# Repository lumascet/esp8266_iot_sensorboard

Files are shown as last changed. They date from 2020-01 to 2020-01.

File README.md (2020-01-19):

# Esp8266 IOT Sensorboard
A IOT Device with lots of sensors publishing acquired data via MQTT with automatic Home Assistant integration.
The board is equipped with following key components: 

* MQ Gas Sensors
    * MQ-3 Alcohol
    * MQ-4 CH4, LPG
    * MQ-7 CO
    * MQ-8 H2
    * MQ-135 Air-Quality
* BME280 Barometric Pressure, Temperature & Humidity
* GMYL8511 UV sensor
* GP2Y1010AU0F Sharp Dust Sensor
* Generic PIR Sensor
* Generic Microphone
* 5528 LDR
* PCF8574 I2C Port Expander
* ADS1115 16 bit ADC
* 74HC4051 8 channel Multiplexer

can be expanded with any other analog or i2c sensors.

Supports ESP8266 Boards NodeMCU & WeMos D1 mini

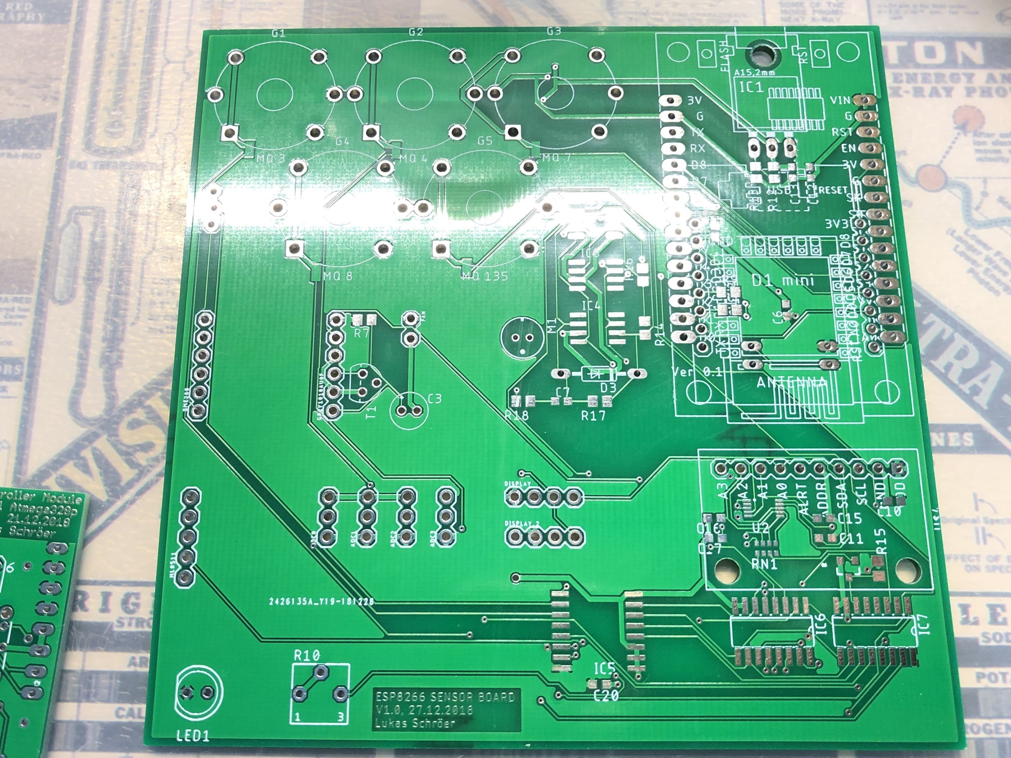
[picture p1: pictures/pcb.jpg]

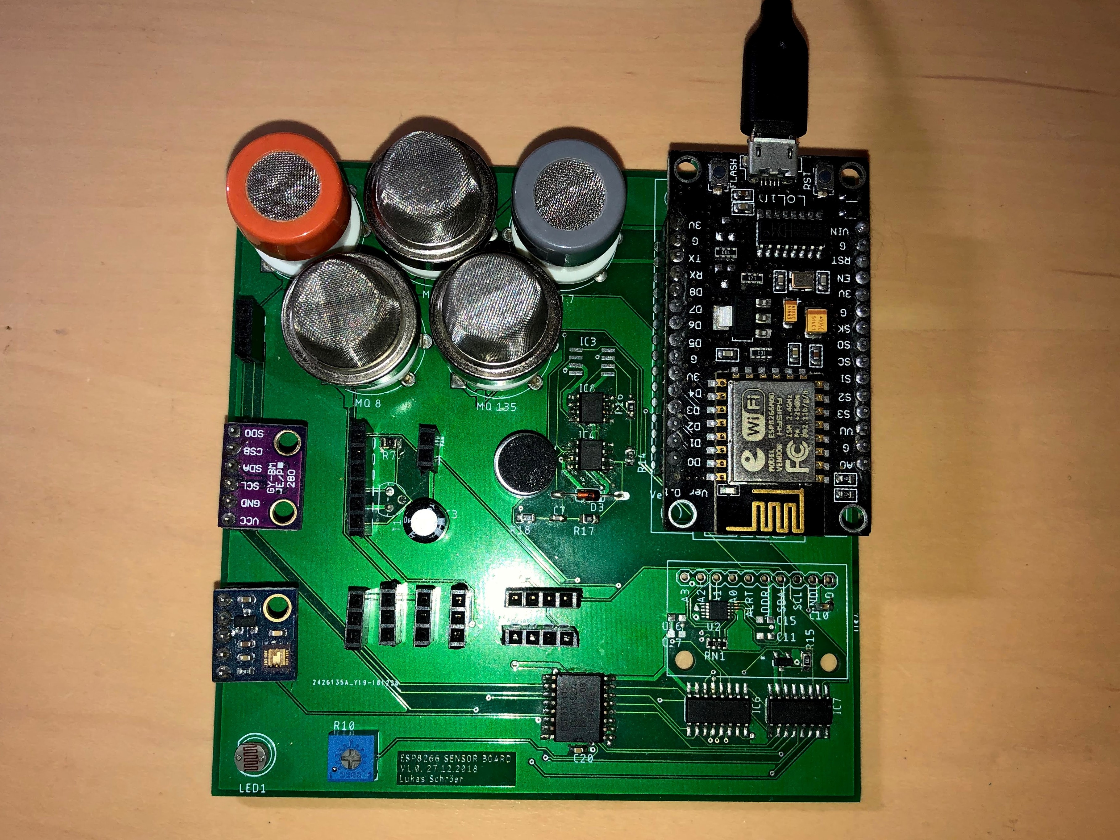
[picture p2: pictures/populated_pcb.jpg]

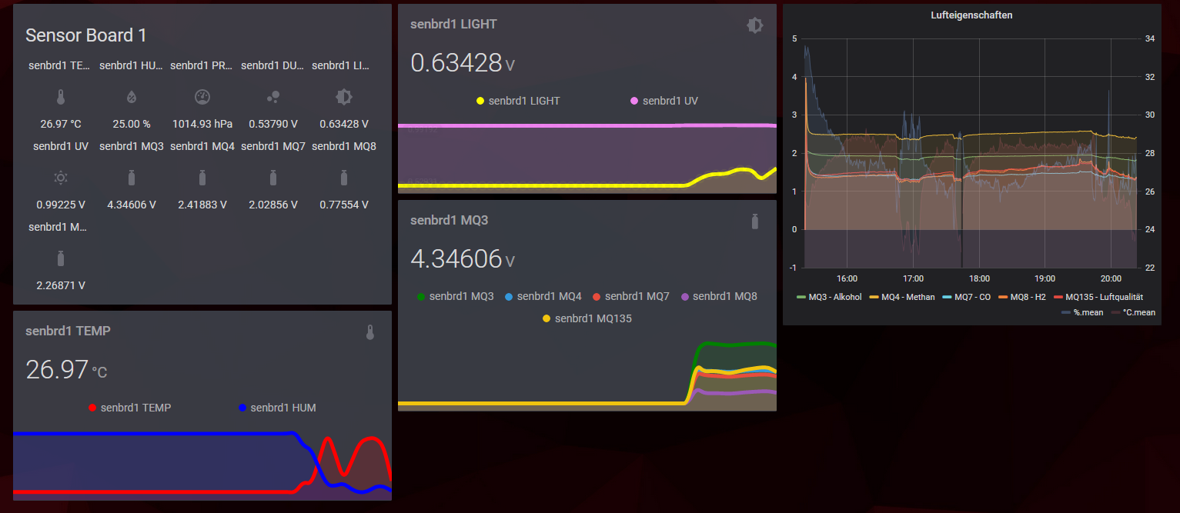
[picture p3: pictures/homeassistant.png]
Homeassistant


# Installation # 

just run the Platformio build task.

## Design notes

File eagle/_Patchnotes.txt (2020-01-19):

-Node MCU changed VIN to VV for 5V Rail
-BME280 too close to gas sensors

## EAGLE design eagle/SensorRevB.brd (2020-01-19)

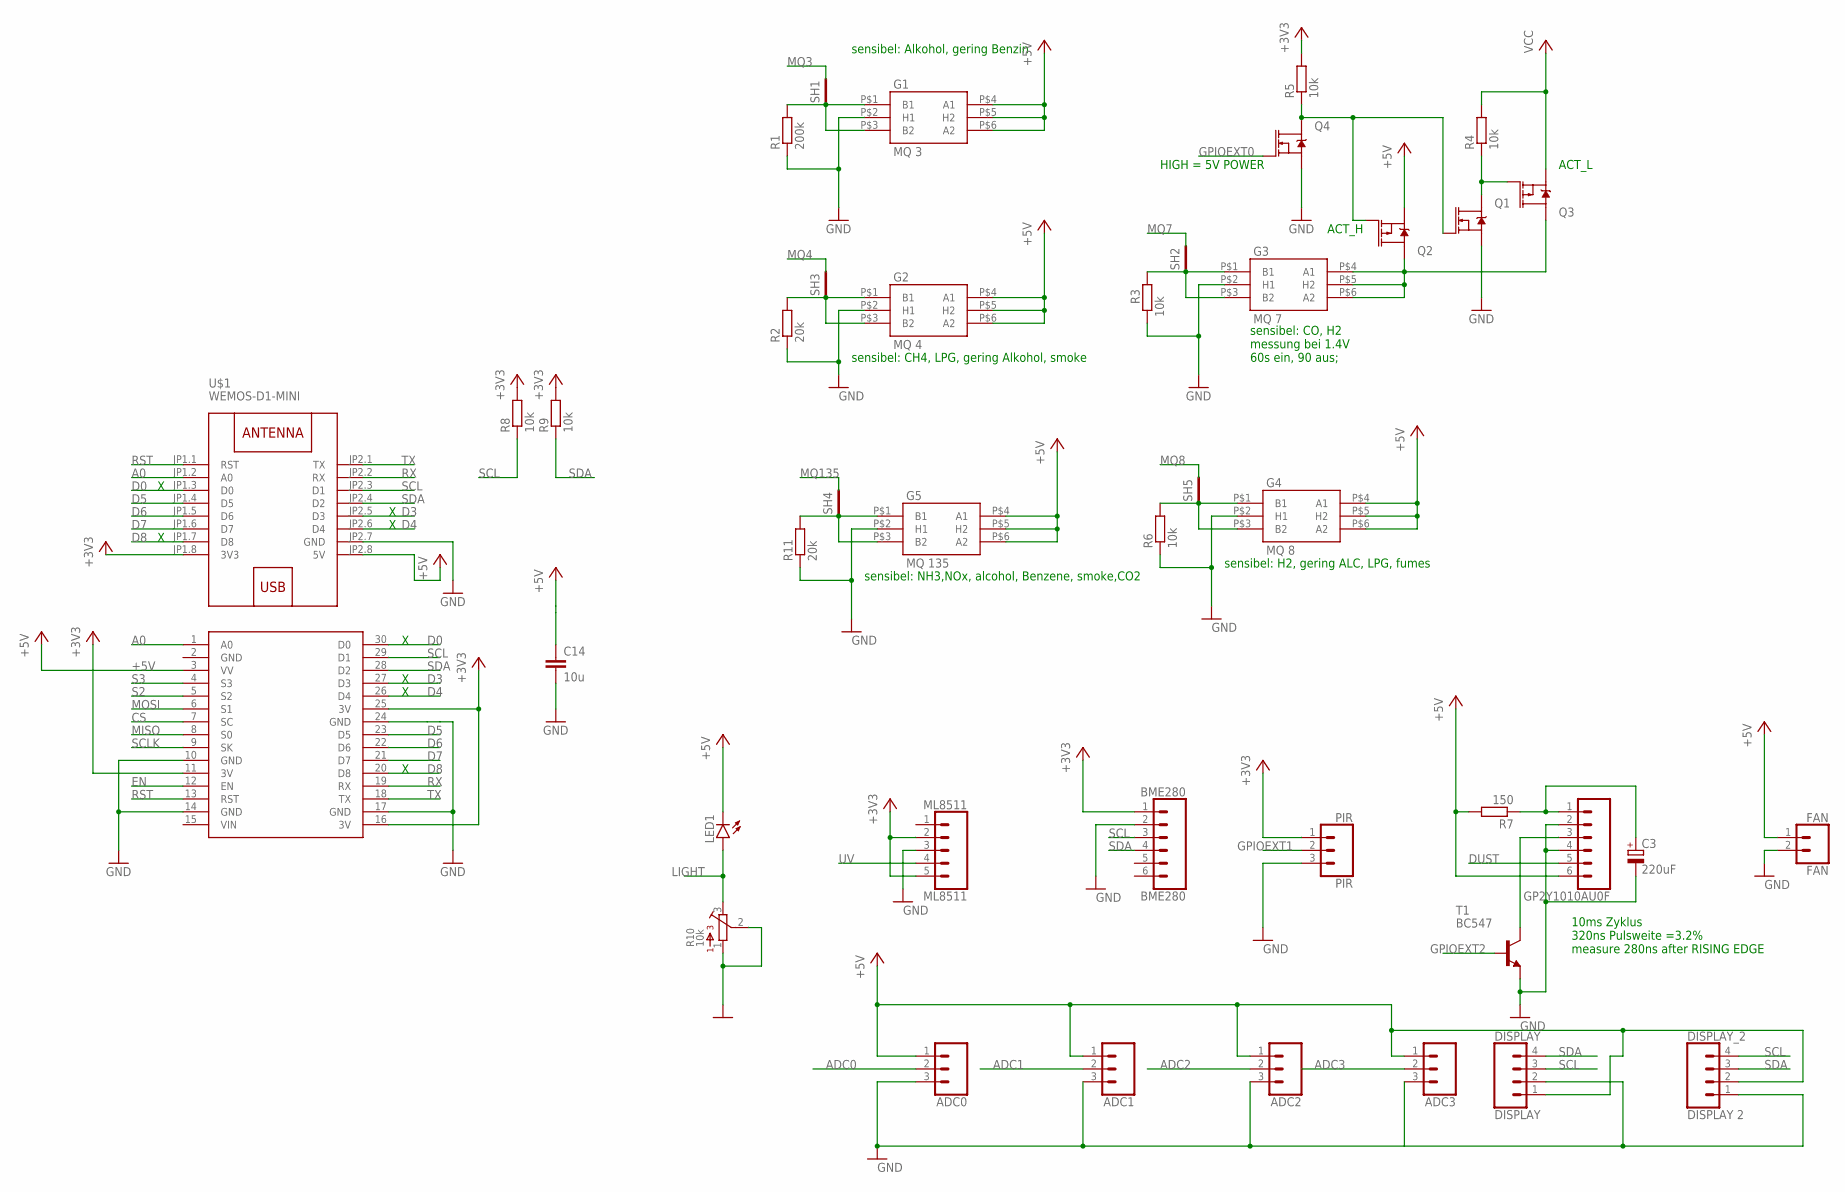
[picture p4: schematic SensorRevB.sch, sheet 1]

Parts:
ADC0, ADC1, ADC2, ADC3: CONN_03; 1X03
BME280: BME280; 1X06
C3: 220uF; E2-5
C14: 10u; C0603
DISPLAY: DISPLAY; 1X04
DISPLAY_2: DISPLAY 2; 1X04
FAN: FAN; 1X02_LOCK
G1: MQ 3; GAS_SOCKET
G2: MQ 4; GAS_SOCKET
G3: MQ 7; GAS_SOCKET
G4: MQ 8; GAS_SOCKET
G5: MQ 135; GAS_SOCKET
GP2Y1010AU0F: CONN_06SILK_FEMALE_PTH; 1X06
LED1: LED5MM
ML8511: ML8511; 1X05
PIR: PIR; 1X03_LOCK
Q1, Q4: 5.8A/30V/35mΩ; SOT23-3
Q2, Q3: 4.3A/20V/54mΩ; SOT23-3
R1: 200k; R0805
R2, R11: 20k; R0805
R3, R4, R5, R6, R8, R9: 10k; R0805
R7: 150; R0805
R10: 10k; 3362P
SH1, SH2, SH3, SH4, SH5: SHORT-HT5; SHORT_TOP-50
T1: BC547; TO92
U$1: WEMOS-D1-MINI
U$2: NODEMCU

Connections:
+3V3: BME280.1, ML8511.2, ML8511.5, PIR.1, R5.2, R8.2, R9.2, U$1.JP1.8 (3V3), U$2.11 (3V), U$2.16 (3V), U$2.25 (3V)
+5V: ADC0.1, ADC1.1, ADC2.1, ADC3.1, C14.1, DISPLAY.1, DISPLAY_2.2, FAN.1, G1.P$4 (A1), G1.P$5 (H2), G1.P$6 (A2), G2.P$4 (A1), G2.P$5 (H2), G2.P$6 (A2), G4.P$4 (A1), G4.P$5 (H2), G4.P$6 (A2), G5.P$4 (A1), G5.P$5 (H2), G5.P$6 (A2), GP2Y1010AU0F.6, LED1.K (C), Q2.2 (S), R7.2, U$1.JP2.8 (5V), U$2.3 (VV); also elsewhere on the board
A0: U$1.JP1.2 (A0), U$2.1 (A0)
ADC0: ADC0.2; also elsewhere on the board
ADC1: ADC1.2; also elsewhere on the board
ADC2: ADC2.2; also elsewhere on the board
ADC3: ADC3.2; also elsewhere on the board
CS: U$2.7 (SC)
D0: U$1.JP1.3 (D0), U$2.30 (D0)
D3: U$1.JP2.5 (D3), U$2.27 (D3)
D4: U$1.JP2.6 (D4), U$2.26 (D4)
D5: U$1.JP1.4 (D5), U$2.23 (D5); also elsewhere on the board
D6: U$1.JP1.5 (D6), U$2.22 (D6)
D7: U$1.JP1.6 (D7), U$2.21 (D7)
D8: U$1.JP1.7 (D8), U$2.20 (D8)
DUST: GP2Y1010AU0F.5; also elsewhere on the board
EN: U$2.12 (EN)
GND: ADC0.3, ADC1.3, ADC2.3, ADC3.3, BME280.2, C3.-, C14.2, DISPLAY.2, DISPLAY_2.1, FAN.2, G1.P$2 (H1), G2.P$2 (H1), G3.P$2 (H1), G4.P$2 (H1), G5.P$2 (H1), GP2Y1010AU0F.2, GP2Y1010AU0F.4, ML8511.3, PIR.3, Q1.2 (S), Q4.2 (S), R1.1, R2.1, R3.1, R6.1, R10.1, R10.2, R11.1, T1.1 (E), U$1.JP2.7 (GND), U$2.2 (GND), U$2.10 (GND), U$2.14 (GND), U$2.17 (GND), U$2.24 (GND); also elsewhere on the board
GPIOEXT0: Q4.1 (G); also elsewhere on the board
GPIOEXT1: PIR.2; also elsewhere on the board
GPIOEXT2: T1.2 (B); also elsewhere on the board
LIGHT: LED1.A, R10.3; also elsewhere on the board
MISO: U$2.8 (S0)
MOSI: U$2.6 (S1)
MQ3: SH1.2; also elsewhere on the board
MQ4: SH3.2; also elsewhere on the board
MQ7: SH2.2; also elsewhere on the board
MQ8: SH5.2; also elsewhere on the board
MQ135: SH4.2; also elsewhere on the board
unnamed: C3.+, GP2Y1010AU0F.1, R7.1
unnamed: GP2Y1010AU0F.3, T1.3 (C)
unnamed: Q1.3 (D), Q3.1 (G), R4.1
unnamed: Q1.1 (G), Q2.1 (G), Q4.3 (D), R5.1
unnamed: G1.P$1 (B1), G1.P$3 (B2), R1.2, SH1.1
unnamed: G3.P$4 (A1), G3.P$5 (H2), G3.P$6 (A2), Q2.3 (D), Q3.3 (D)
unnamed: G3.P$1 (B1), G3.P$3 (B2), R3.2, SH2.1
unnamed: G2.P$1 (B1), G2.P$3 (B2), R2.2, SH3.1
unnamed: G5.P$1 (B1), G5.P$3 (B2), R11.2, SH4.1
unnamed: G4.P$1 (B1), G4.P$3 (B2), R6.2, SH5.1
RST: U$1.JP1.1 (RST), U$2.13 (RST)
RX: U$1.JP2.2 (RX), U$2.19 (RX)
S2: U$2.5 (S2)
S3: U$2.4 (S3)
SCL: BME280.3, DISPLAY.3, DISPLAY_2.4, R8.1, U$1.JP2.3 (D1), U$2.29 (D1); also elsewhere on the board
SCLK: U$2.9 (SK)
SDA: BME280.4, DISPLAY.4, DISPLAY_2.3, R9.1, U$1.JP2.4 (D2), U$2.28 (D2); also elsewhere on the board
TX: U$1.JP2.1 (TX), U$2.18 (TX)
UV: ML8511.4; also elsewhere on the board
VCC: Q3.2 (S), R4.2; also elsewhere on the board

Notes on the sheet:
sensibel: Alkohol, gering Benzin
sensibel: CH4, LPG, gering Alkohol, smoke
sensibel: CO, H2 messung bei 1.4V 60s ein, 90 aus;
ACT_H
ACT_L
HIGH = 5V POWER
sensibel: H2, gering ALC, LPG, fumes
sensibel: NH3,NOx, alcohol, Benzene, smoke,CO2
10ms Zyklus 320ns Pulsweite =3.2% measure 280ns after RISING EDGE

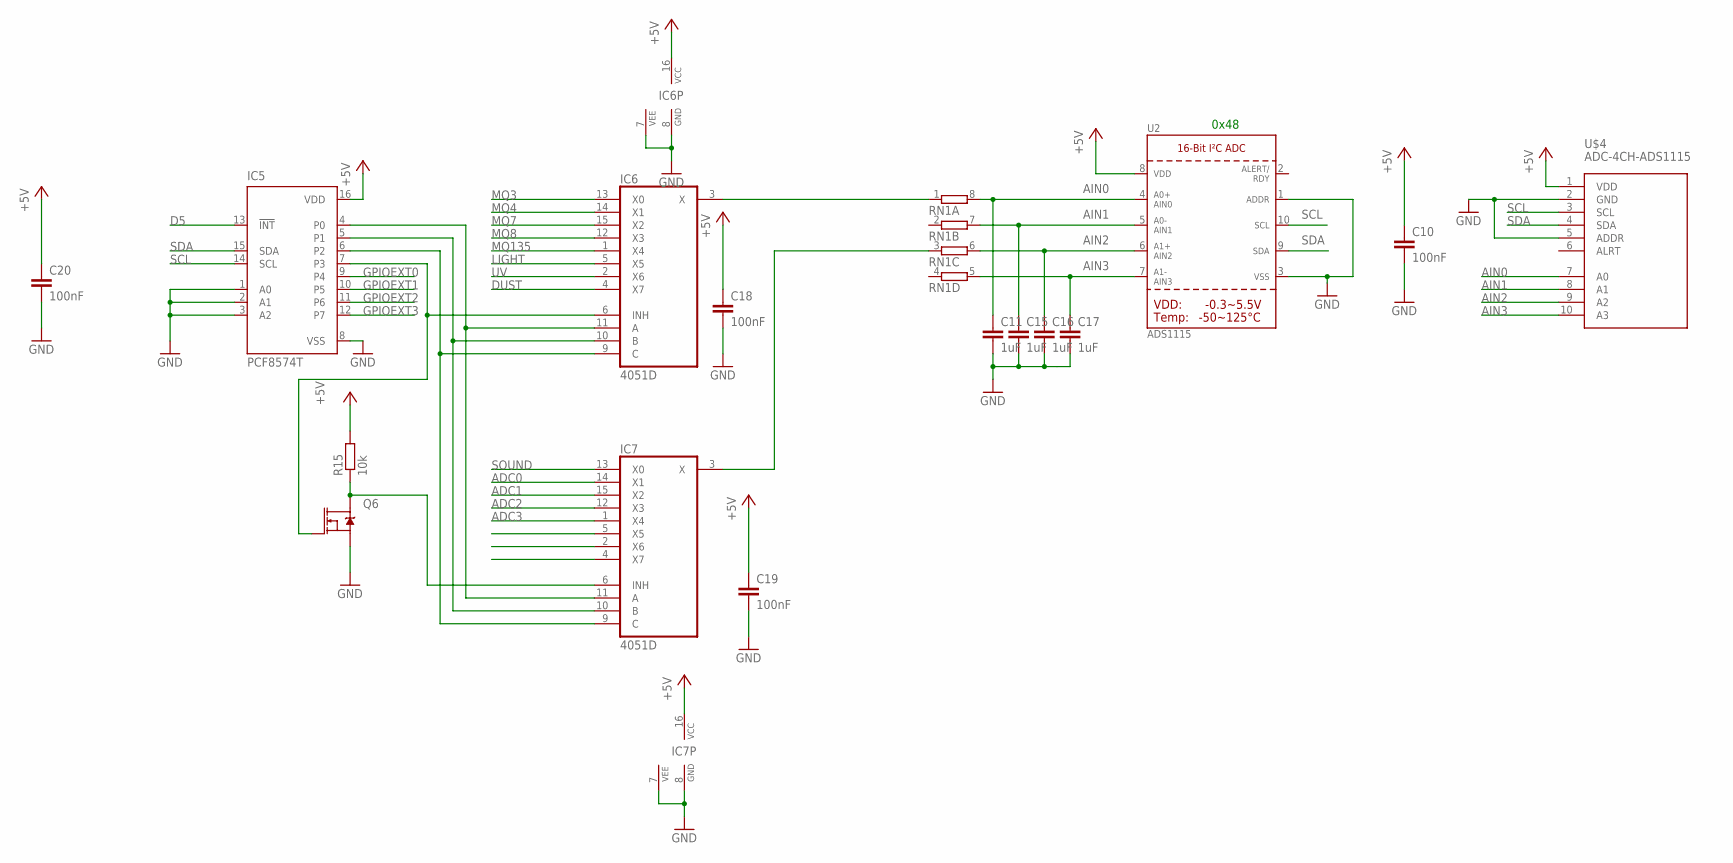
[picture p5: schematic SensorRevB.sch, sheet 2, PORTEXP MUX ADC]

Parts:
C10, C18, C19, C20: 100nF; C0603
C11, C15, C16, C17: 1uF; C0603
IC5: PCF8574T; SO16W
IC6, IC7: 4051D; SO16
Q6: 5.8A/30V/35mΩ; SOT23-3
R15: 10k; R0805
RN1: 4R-N0603-ARC; 0603-ARC
U2: ADS1115; MSOP10
U$4: ADC-4CH-ADS1115

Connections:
+5V: C10.1, C18.1, C19.1, C20.1, IC5.16 (VDD), IC6.16 (VCC), IC7.16 (VCC), R15.2, U2.8 (VDD), U$4.1 (VDD); also elsewhere on the board
ADC0: IC7.14 (X1); also elsewhere on the board
ADC1: IC7.15 (X2); also elsewhere on the board
ADC2: IC7.12 (X3); also elsewhere on the board
ADC3: IC7.1 (X4); also elsewhere on the board
AIN0: C11.1, RN1.8 (2), U2.4 (AIN0), U$4.7 (A0)
AIN1: C15.1, RN1.7 (2), U2.5 (AIN1), U$4.8 (A1)
AIN2: C16.1, RN1.6 (2), U2.6 (AIN2), U$4.9 (A2)
AIN3: C17.1, RN1.5 (2), U2.7 (AIN3), U$4.10 (A3)
D5: IC5.13 (!INT); also elsewhere on the board
DUST: IC6.4 (X7); also elsewhere on the board
GND: C10.2, C11.2, C15.2, C16.2, C17.2, C18.2, C19.2, C20.2, IC5.1 (A0), IC5.2 (A1), IC5.3 (A2), IC5.8 (VSS), IC6.7 (VEE), IC6.8 (GND), IC7.7 (VEE), IC7.8 (GND), Q6.2 (S), U2.1 (ADDR), U2.3 (VSS), U$4.2 (GND), U$4.5 (ADDR); also elsewhere on the board
GPIOEXT0: IC5.9 (P4); also elsewhere on the board
GPIOEXT1: IC5.10 (P5); also elsewhere on the board
GPIOEXT2: IC5.11 (P6); also elsewhere on the board
GPIOEXT3: IC5.12 (P7)
LIGHT: IC6.5 (X5); also elsewhere on the board
MQ3: IC6.13 (X0); also elsewhere on the board
MQ4: IC6.14 (X1); also elsewhere on the board
MQ7: IC6.15 (X2); also elsewhere on the board
MQ8: IC6.12 (X3); also elsewhere on the board
MQ135: IC6.1 (X4); also elsewhere on the board
unnamed: IC5.4 (P0), IC6.11 (A), IC7.11 (A)
unnamed: IC5.5 (P1), IC6.10 (B), IC7.10 (B)
unnamed: IC5.6 (P2), IC6.9 (C), IC7.9 (C)
unnamed: IC5.7 (P3), IC6.6 (INH), Q6.1 (G)
unnamed: IC7.6 (INH), Q6.3 (D), R15.1
unnamed: IC6.3 (X), RN1.1
unnamed: IC7.3 (X), RN1.3 (1)
SCL: IC5.14 (SCL), U2.10 (SCL), U$4.3 (SCL); also elsewhere on the board
SDA: IC5.15 (SDA), U2.9 (SDA), U$4.4 (SDA); also elsewhere on the board
SOUND: IC7.13 (X0); also elsewhere on the board
UV: IC6.2 (X6); also elsewhere on the board

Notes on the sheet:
0x48

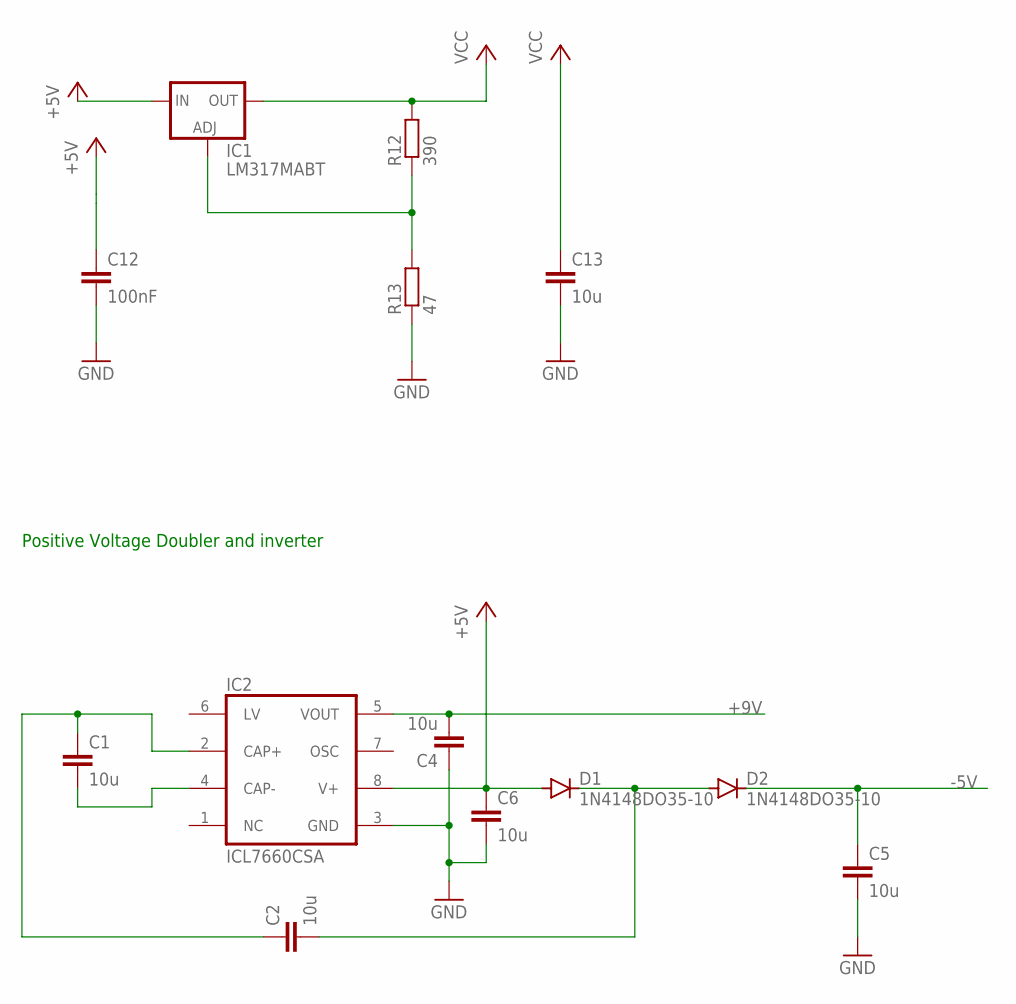
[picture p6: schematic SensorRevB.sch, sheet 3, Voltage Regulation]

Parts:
C1, C2, C4, C5, C6, C13: 10u; C0603
C12: 100nF; C0603
D1, D2: 1N4148DO35-10; DO35-10
IC1: LM317MABT; TO220L1
IC2: ICL7660CSA; SO08
R12: 390; R0805
R13: 47; R0805

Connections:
+5V: C6.1, C12.1, D1.A, IC1.3 (IN), IC2.8 (V+); also elsewhere on the board
+9V: C4.2, IC2.5 (VOUT); also elsewhere on the board
-5V: C5.1, D2.C; also elsewhere on the board
GND: C4.1, C5.2, C6.2, C12.2, C13.2, IC2.3 (GND), R13.1; also elsewhere on the board
unnamed: C1.1, C2.1, IC2.2 (CAP+)
unnamed: C1.2, IC2.4 (CAP-)
unnamed: IC1.1 (ADJ), R12.1, R13.2
unnamed: C2.2, D1.C, D2.A
VCC: C13.1, IC1.2 (OUT), R12.2; also elsewhere on the board

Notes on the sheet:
Positive Voltage Doubler and inverter

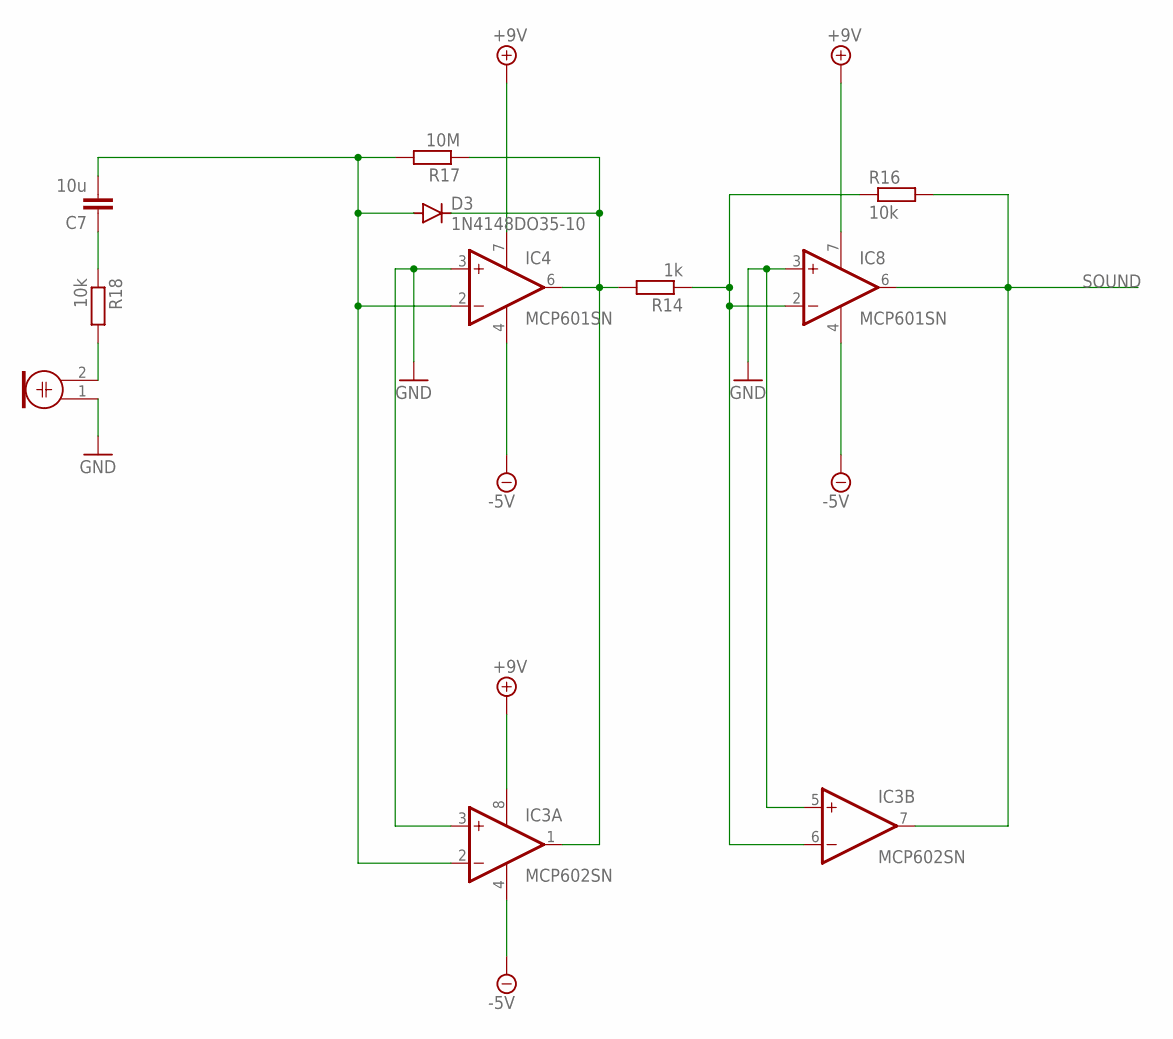
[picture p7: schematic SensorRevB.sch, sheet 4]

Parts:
C7: 10u; C0603
D3: 1N4148DO35-10; DO35-10
IC3: MCP602SN; SO08
IC4, IC8: MCP601SN; SO08
M1: ELECTRET_MICROPHON-WM-61B; WM-61B
R14: 1k; R0805
R16, R18: 10k; R0805
R17: 10M; R0805

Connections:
+9V: IC3.8 (V+), IC4.7 (V+), IC8.7 (V+); also elsewhere on the board
-5V: IC3.4 (V-), IC4.4 (V-), IC8.4 (V-); also elsewhere on the board
GND: IC3.3 (+IN), IC3.5 (+IN), IC4.3 (+IN), IC8.3 (+IN), M1.1; also elsewhere on the board
unnamed: IC3.6 (-IN), IC8.2 (-IN), R14.1, R16.1
unnamed: D3.C, IC3.1 (OUT), IC4.6 (OUT), R14.2, R17.1
unnamed: C7.1, R18.1
unnamed: C7.2, D3.A, IC3.2 (-IN), IC4.2 (-IN), R17.2
unnamed: M1.2, R18.2
SOUND: IC3.7 (OUT), IC8.6 (OUT), R16.2; also elsewhere on the board

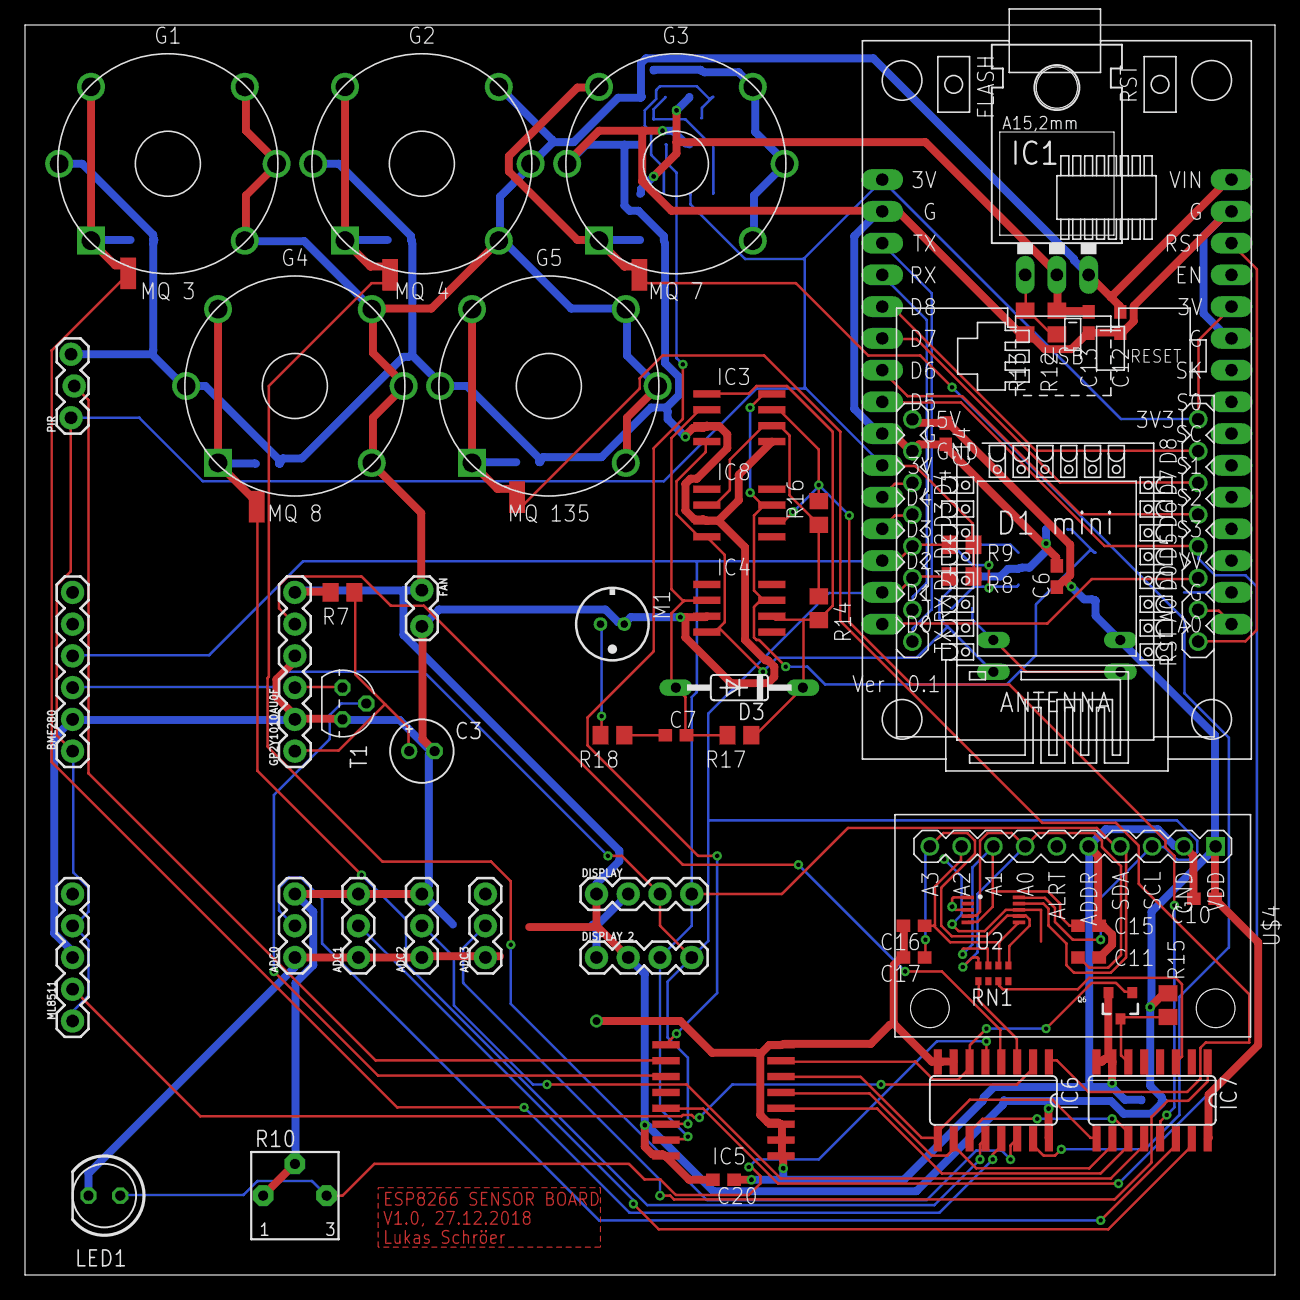
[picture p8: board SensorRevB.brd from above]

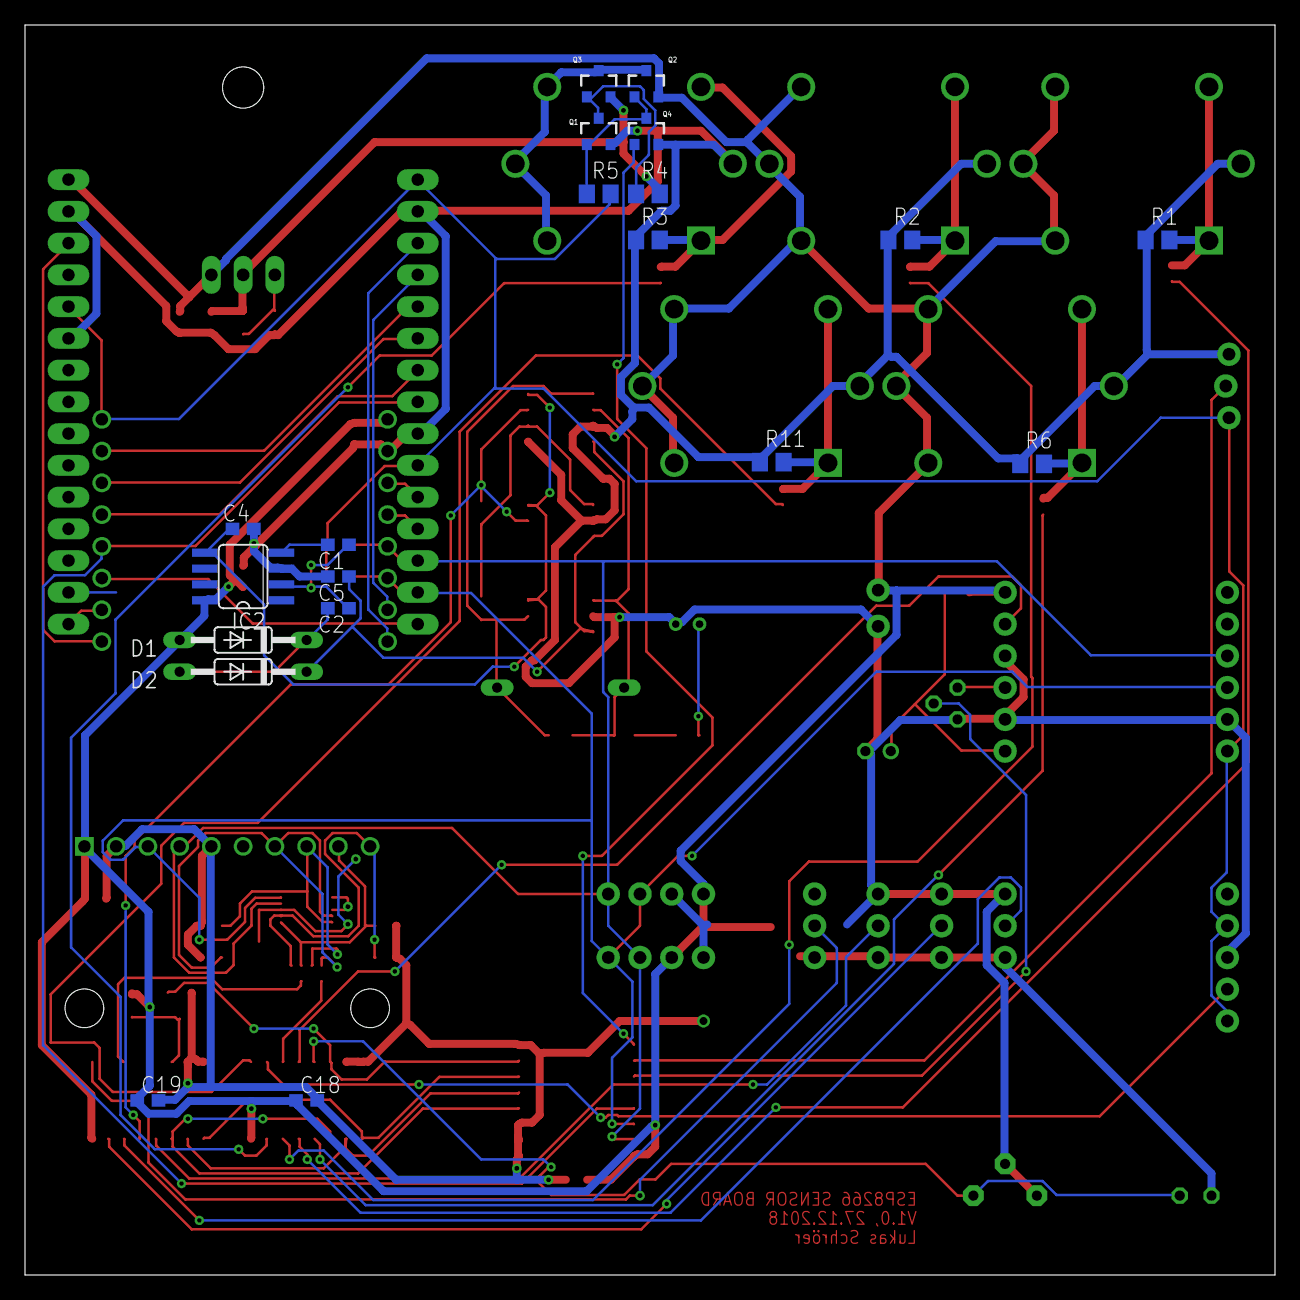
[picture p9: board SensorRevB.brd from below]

Board: 2 copper layers, 100.0 x 100.0 mm, 81 parts (20 on the bottom side), 65 nets.

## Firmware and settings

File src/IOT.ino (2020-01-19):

#include <ESP8266WiFi.h>
#include <PubSubClient.h>
#include <ArduinoJson.h>

#include <Wire.h>
#include <Adafruit_ADS1015.h>
#include <Adafruit_Sensor.h>
#include <Adafruit_BME280.h>

#include <IoAbstraction.h>
#include <IoAbstractionWire.h>

#define _TASK_SLEEP_ON_IDLE_RUN
#include <TaskScheduler.h>

void dustPwmCallback();
void coPwmCallback();
void mqttServiceCallback();
void sensorCallback();
void blinkled();

typedef enum sensors_e{
  MQ3,
  MQ4,
  MQ7,
  MQ8,
  MQ135,
  LIGHT,
  UV,
  DUST,
  SOUND,
  TEMP,
  HUM,
  PRES
}sensors_t;


/************************* Tasks *********************************/

Scheduler runner;

Task t1(10, TASK_FOREVER, &dustPwmCallback, &runner, true);
//Task t2(60000, TASK_FOREVER, &coPwmCallback, &runner, true);
//Task t3(90000, TASK_FOREVER, &coPwmCallback, &runner, true);
Task t4(1000, TASK_FOREVER, &sensorCallback, &runner, true);
Task t5(5000, TASK_FOREVER, &mqttServiceCallback, &runner, true);
Task t6(500, 4, &blinkled, &runner, true);

/************************* I2C Devices *********************************/

#define ADDR_PEX  0x20
#define ADDR_ADC  0x48
#define ADDR_BME  0x76


Adafruit_ADS1115 adc;
Adafruit_BME280 bme;
IoAbstractionRef ioExpander = ioFrom8574(ADDR_PEX);


/************************* Global Sensor Variables *********************************/

unsigned int data_chache[16][5];
float data_bme[3];
bool  control_reg[1] = {0}; //{bme enable bit,
bool ready = 0;

/************************* WiFi Access Point *********************************/

#include "credentials.h"

const char* ssid = SSID;
const char* password = PWD;
const char* mqtt_server = MQTT_IP;
const char* clientUsr = MQTT_USER;
const char* clientPw = MQTT_PWD;
WiFiClient espClient;
PubSubClient client(espClient);
long lastMsg = 0;
char msg[50];
int value = 0;

String BOARDNAME = "senbrd1";
String MTYPE = "sensor";
String HOMEPREFIX = "homeassistant";
String UUID = (String)ESP.getChipId();
String VERSION = "V2.0";

String MQ3_topic = "MQ3";
String MQ4_topic = "MQ4";
String MQ7_topic = "MQ7";
String MQ8_topic = "MQ8";
String MQ135_topic = "MQ135";
String LIGHT_topic = "LIGHT";
String UV_topic = "UV";
String DUST_topic = "DUST";
String SOUND_topic = "SOUND";
String TEMP_topic = "TEMP";
String HUM_topic = "HUM";
String PRES_topic = "PRES";
String sensor_suffix[] ={
  MQ3_topic,
  MQ4_topic,
  MQ7_topic,
  MQ8_topic,
  MQ135_topic,
  LIGHT_topic,
  UV_topic,
  DUST_topic,
  SOUND_topic,
  TEMP_topic,
  HUM_topic,
  PRES_topic
};
String sensor_unit[] ={
  "V",
  "V",
  "V",
  "V",
  "V",
  "V",
  "V",
  "V",
  "V",
  "°C",
  "%",
  "hPa"
};
String sensor_icon[]{
  "mdi:gas-cylinder",
  "mdi:gas-cylinder",
  "mdi:gas-cylinder",
  "mdi:gas-cylinder",
  "mdi:gas-cylinder",
  "mdi:brightness-6",
  "mdi:weather-sunny",
  "mdi:chart-bubble",
  "mdi:volume-high",
  "mdi:thermometer",
  "mdi:water-percent",
  "mdi:gauge"
};


//https://arduinojson.org/v6/assistant/

void switchDiscovery(){
  char topic_buffer[50], payload_buffer[300];
  const size_t capacity = JSON_ARRAY_SIZE(1) + JSON_OBJECT_SIZE(1) + JSON_OBJECT_SIZE(15);
  DynamicJsonDocument doc(capacity);

  doc["~"] = BOARDNAME + "/";
  doc["name"] = BOARDNAME;
  doc["cmd_t"] = "~cmnd/POWER";
  doc["stat_t"] = "~tele/STATE";
  doc["val_tpl"] = "{{value}}";
  doc["pl_off"] = "OFF";
  doc["pl_on"] = "ON";
  doc["avty_t"] = "~tele/LWT";
  doc["pl_avail"] = "Online";
  doc["pl_not_avail"] = "Offline";
  doc["uniq_id"] = UUID + "_switch";

  JsonObject device = doc.createNestedObject("device");
  JsonArray device_identifiers = device.createNestedArray("identifiers");
  device_identifiers.add(UUID);

  serializeJson(doc, payload_buffer);
  sprintf(topic_buffer, "%s/%s/%s/%s", HOMEPREFIX.c_str(), "switch",(UUID + "_switch").c_str(), "config");
  client.publish(topic_buffer, payload_buffer, strlen(payload_buffer));
}

void statusDiscovery(){
  char topic_buffer[50], payload_buffer[1000];
  const size_t capacity = JSON_ARRAY_SIZE(1) + JSON_OBJECT_SIZE(5) + JSON_OBJECT_SIZE(20);
  DynamicJsonDocument doc(capacity);

  doc["name"] = BOARDNAME + " status";
  doc["stat_t"] = "~HASS_STATE";
  doc["avty_t"] = "~LWT";
  doc["pl_avail"] = "Online";
  doc["pl_not_avail"] = "Offline";
  doc["json_attributes_topic"] = "~HASS_STATE";
  doc["unit_of_meas"] = " ";
  doc["val_tpl"] = "{{value_json['RSSI']}}";
  doc["uniq_id"] = UUID + "_status";

  JsonObject device = doc.createNestedObject("device");
  JsonArray device_identifiers = device.createNestedArray("identifiers");
  device_identifiers.add(UUID);
  device["name"] = BOARDNAME;
  device["model"] = "DIY Sensorboard";
  device["sw_version"] = VERSION;
  device["manufacturer"] = "Lukas Schröer";
  doc["~"] = BOARDNAME + "/tele/";

  serializeJson(doc, payload_buffer);
  //strcpy(payload_buffer,"{\"name\":\"senbrd1 status\",\"stat_t\":\"~HASS_STATE\",\"avty_t\":\"~LWT\",\"pl_avail\":\"Online\",\"pl_not_avail\":\"Offline\",\"json_attributes_topic\":\"~HASS_STATE\",\"unit_of_meas\":\" \",\"val_tpl\":\"{{value_json['RSSI']}}\",\"uniq_id\":\"3998661_status\",\"device\":{\"identifiers\":[\"3998661\"],\"name\":\"senbrd1\",\"model\":\"DIY Sensorboard\"}}");
  //strcpy(payload_buffer,"{\"name\":\"senbrd1 status\",\"pl_avail\":\"Online\",\"pl_not_avail\":\"Offline\",\"json_attributes_topic\":\"~HASS_STATE\",\"unit_of_meas\":\" \",\"val_tpl\":\"{{value_json['RSSI']}}\",\"uniq_id\":\"3998661_status\",\"device\":{\"identifiers\":[\"3998661\"],\"name\":\"senbrd1\",\"model\":\"DIY Sensorboard\"}}");
  sprintf(topic_buffer, "%s/%s/%s/%s", HOMEPREFIX.c_str(), "sensor", (UUID + "_status").c_str(), "config");
  Serial.println(topic_buffer);
  Serial.println(payload_buffer);
  client.publish(topic_buffer, payload_buffer, strlen(payload_buffer));
}

void hassStatePublish(){
  char topic_buffer[50], payload_buffer[1000];
  const size_t capacity = JSON_OBJECT_SIZE(15);
  DynamicJsonDocument doc(capacity);

  doc["Version"] = VERSION;
  doc["BuildDateTime"] = __TIME__;
  doc["Module"] = BOARDNAME;
  doc["Uptime"] = millis();
  doc["IPAddress"] = WiFi.localIP().toString();
  doc["RSSI"] = WiFi.RSSI();

  serializeJson(doc, payload_buffer);
  sprintf(topic_buffer, "%s/%s/%s", BOARDNAME.c_str(), "tele", "HASS_STATE");
  client.publish(topic_buffer, payload_buffer, strlen(payload_buffer));
}

void sensorConfigDiscovery(String name, String unit, String icon){
  char topic_buffer[50], payload_buffer[1000];
  String uniqid = UUID + "_" + name;
  uniqid.replace(' ', '_');
  const size_t capacity = JSON_ARRAY_SIZE(1) + JSON_OBJECT_SIZE(1) + JSON_OBJECT_SIZE(16);
  DynamicJsonDocument doc(capacity);

  doc["name"] = BOARDNAME + " " + name;
  doc["stat_t"] = "~" + name;
  doc["avty_t"] = "~LWT";
  doc["val_tpl"] = "{{value}}";
  doc["pl_avail"] = "Online";
  doc["pl_not_avail"] = "Offline";
  doc["uniq_id"] = uniqid;

  JsonObject device = doc.createNestedObject("device");
  JsonArray device_identifiers = device.createNestedArray("identifiers");
  device_identifiers.add(UUID);
  doc["~"] = BOARDNAME + "/tele" + "/";
  doc["unit_of_meas"] = unit;
  doc["icon"] = icon;

  serializeJson(doc, payload_buffer);
  sprintf(topic_buffer, "%s/%s/%s/%s", HOMEPREFIX.c_str(), "sensor", uniqid.c_str(), "config");
  client.publish(topic_buffer, payload_buffer, strlen(payload_buffer));
}

void setupDiscovery(){
  switchDiscovery();
  statusDiscovery();
  for(int i=0; i<sizeof(sensor_suffix)/sizeof(sensor_suffix[0]); i++){
    sensorConfigDiscovery(sensor_suffix[i], sensor_unit[i], sensor_icon[i]);
  }
}


void setup_wifi() {

  delay(10);
  // We start by connecting to a WiFi network
  Serial.println();
  Serial.print("Connecting to ");
  Serial.println(ssid);

  WiFi.begin(ssid, password);
  int i=0;
  while (WiFi.status() != WL_CONNECTED) {
    delay(500);
    Serial.print(".");
    i++;
    if(i>100)
      ESP.restart();
  }

  randomSeed(micros());

  Serial.println("");
  Serial.println("WiFi connected");
  Serial.println("IP address: ");
  Serial.println(WiFi.localIP());
}

void reconnect() {
  // Loop until we're reconnected
  while (!client.connected()) {
    Serial.print("Attempting MQTT connection...");
    // Create a random client ID
    String clientId = "ESP8266Client-";
    clientId += String(random(0xffff), HEX);
    // Attempt to connect
    if (client.connect(clientId.c_str(), clientUsr, clientPw, (BOARDNAME + "/tele/LWT").c_str(), 0, 0, "Offline")) {
      Serial.println("connected");
      // Once connected, publish an announcement...
      client.publish((BOARDNAME + "/tele/LWT").c_str(), "Online");
    } else {
      Serial.print("failed, rc=");
      Serial.print(client.state());
      Serial.println(" try again in 5 seconds");
      // Wait 5 seconds before retrying
      delay(5000);
    }
  }
}

void setup(void)
{
  Serial.begin(115200);
  pinMode(LED_BUILTIN, OUTPUT);     // Initialize the LED_BUILTIN pin as an output
  setup_wifi();
  client.setServer(mqtt_server, 1883);
  reconnect();
  setupDiscovery();

  Wire.begin();

  ioDevicePinMode(ioExpander, 0, OUTPUT);
  ioDevicePinMode(ioExpander, 1, OUTPUT);
  ioDevicePinMode(ioExpander, 2, OUTPUT);
  ioDevicePinMode(ioExpander, 3, OUTPUT);
  ioDevicePinMode(ioExpander, 4, OUTPUT);
  ioDevicePinMode(ioExpander, 5, INPUT);
  ioDevicePinMode(ioExpander, 6, OUTPUT);
  ioDevicePinMode(ioExpander, 7, OUTPUT);
  pinMode(D5, OUTPUT);

  ioDeviceDigitalWrite(ioExpander, 0, 0); //A
  ioDeviceDigitalWrite(ioExpander, 1, 0); //B
  ioDeviceDigitalWrite(ioExpander, 2, 0); //C
  ioDeviceDigitalWrite(ioExpander, 3, 0); //EN, ACTIVE LOW
  ioDeviceDigitalWrite(ioExpander, 4, 1); //EN, ACTIVE LOW

  // The ADC input range (or gain) can be changed via the following
  // functions, but be careful never to exceed VDD +0.3V max, or to
  // exceed the upper and lower limits if you adjust the input range!
  // Setting these values incorrectly may destroy your ADC!
  //                                                                ADS1015  ADS1115
  //                                                                -------  -------
   adc.setGain(GAIN_TWOTHIRDS);  // 2/3x gain +/- 6.144V  1 bit = 3mV      0.1875mV (default)
  // adc.setGain(GAIN_ONE);        // 1x gain   +/- 4.096V  1 bit = 2mV      0.125mV
  // adc.setGain(GAIN_TWO);        // 2x gain   +/- 2.048V  1 bit = 1mV      0.0625mV
  // adc.setGain(GAIN_FOUR);       // 4x gain   +/- 1.024V  1 bit = 0.5mV    0.03125mV
  // adc.setGain(GAIN_EIGHT);      // 8x gain   +/- 0.512V  1 bit = 0.25mV   0.015625mV
  // adc.setGain(GAIN_SIXTEEN);    // 16x gain  +/- 0.256V  1 bit = 0.125mV  0.0078125mV

  digitalWrite(LED_BUILTIN, 1);

  Wire.beginTransmission(ADDR_PEX);
  if (Wire.endTransmission()!=0) {
        Serial.println("Could not find PCF8574 Port Expander!");
        while (1);
  }
  ioDeviceSync(ioExpander);
  Serial.println("Port Expander connected.");

  Wire.beginTransmission(ADDR_ADC);
  if (Wire.endTransmission()!=0) {
        Serial.println("Could not find ADS1115 ADC!");
        while (1);
  }
  adc.begin();
  Serial.println("ADC connected.");

  Wire.beginTransmission(ADDR_BME);
  if (Wire.endTransmission()!=0) {
      Serial.println("Could not find a valid BME280 sensor, ignoring!");
      control_reg[0] = 0;
  }
  else{
    bme.begin(ADDR_BME);
    control_reg[0] = 1;
    Serial.println("BME280 connected.");
    bme.setSampling(Adafruit_BME280::MODE_NORMAL,
                  Adafruit_BME280::SAMPLING_X16,  // temperature
                  Adafruit_BME280::SAMPLING_X16, // pressure
                  Adafruit_BME280::SAMPLING_X16,  // humidity
                  Adafruit_BME280::FILTER_X16,
                  Adafruit_BME280::STANDBY_MS_0_5 );
  }


  t5.delay(15001);
  runner.startNow();
}


void loop(){
  if (!client.connected()) {
     reconnect();
   }
  client.loop();
  ioDeviceSync(ioExpander);
  runner.execute();

}

void blinkled(){
  static bool state = 1;
  state = !state;
  digitalWrite(LED_BUILTIN, state);
}

void dustPwmCallback(){

  static int dim = -1;
  dim++;
  if(dim==5)
    dim = 0;

  ioDeviceDigitalWrite(ioExpander, 0, 1); //A
  ioDeviceDigitalWrite(ioExpander, 1, 1); //B
  ioDeviceDigitalWrite(ioExpander, 2, 1); //C
  ioDeviceDigitalWrite(ioExpander, 3, 0); //EN, ACTIVE LOW
  //ioDeviceDigitalWrite(ioExpander, 6, 1);
  digitalWrite(D5, 1);
  ioDeviceSync(ioExpander);

  delayMicroseconds(280);
  data_chache[7][dim] = adc.readADC_SingleEnded(0);
  delayMicroseconds(40);

  //ioDeviceDigitalWrite(ioExpander, 6, 0);
  digitalWrite(D5, 0);
  ioDeviceSync(ioExpander);
}


void sensorCallback(){

  #define LAST_SENSOR 14

  static int dim = -1;
  dim++;
  if(dim==5){
    ready = 1;
    dim = 0;
  }

  int i;
  for(i=0; i<=16;i++){

    ioDeviceDigitalWrite(ioExpander, 0, (i >> 0) & 1); //A
    ioDeviceDigitalWrite(ioExpander, 1, (i >> 1) & 1); //B
    ioDeviceDigitalWrite(ioExpander, 2, (i >> 2) & 1); //C
    ioDeviceDigitalWrite(ioExpander, 3, ((i >> 3) & 1)); //EN, ACTIVE LOW
    ioDeviceSync(ioExpander);

    if(i!=16){
      delayMicroseconds(500);
    }

    if(i==LAST_SENSOR)
      i = 16;
    if(i==7)
      continue; //skip
    else if(i<8)
      data_chache[i][dim] = adc.readADC_SingleEnded(0);
    else if(i <16)
      data_chache[i][dim] = adc.readADC_SingleEnded(2);
  }
  if(control_reg[0]){
    data_bme[0] = bme.readTemperature();
    data_bme[1] = bme.readPressure()/100;
    data_bme[2] = bme.readHumidity();
  }


}

void mqttServiceCallback(){
  bool state = 0;
  float data_cache_sum[16];

  if(!ready) return;

  for(int i=0; i<16; i++){
    data_cache_sum[i]=0;
    for(int j=0; j<5; j++){
      if(data_chache[i][j] <= 0x7FFF)
        data_cache_sum[i] += data_chache[i][j] * 0.0001875;
      else
        data_cache_sum[i] += ((float)data_chache[i][j] - (float)0xFFFF) * 0.0001875;
    }
    data_cache_sum[i] = data_cache_sum[i]/5;
  }

  char topic[50], payload[10];
  for(int i=0; i<(sizeof(sensor_suffix)/sizeof(sensor_suffix[0])-3); i++){
    snprintf(payload, sizeof(payload), "%.5f", data_cache_sum[i]);
    strcpy(topic,(BOARDNAME + "/tele/" + sensor_suffix[i]).c_str());
    //snprintf(topic, sizeof(topic), "%s", tmp);
    client.publish(topic, payload);
  }

  if(control_reg[0]){
    snprintf(payload, sizeof(payload), "%.2f", data_bme[0]);
    strcpy(topic,(BOARDNAME + "/tele/" + sensor_suffix[TEMP]).c_str());
    client.publish(topic, payload);
    snprintf(payload, sizeof(payload), "%.2f", data_bme[1]);
    strcpy(topic,(BOARDNAME + "/tele/" + sensor_suffix[PRES]).c_str());
    client.publish(topic, payload);
    snprintf(payload, sizeof(payload), "%.2f", data_bme[2]);
    strcpy(topic,(BOARDNAME + "/tele/" + sensor_suffix[HUM]).c_str());
    client.publish(topic, payload);
  }
  hassStatePublish();
  /*
  MQ3.publish(data_cache_sum[0], 5);
  MQ4.publish(data_cache_sum[1], 5);
  MQ7.publish(data_cache_sum[2], 5);
  MQ8.publish(data_cache_sum[3], 5);
  MQ135.publish(data_cache_sum[4], 5);
  LIGHT.publish(data_cache_sum[5], 5);
  UV.publish(data_cache_sum[6], 5);
  DUST.publish(data_cache_sum[7], 5);
  SOUND.publish(data_cache_sum[8], 5);
  if(control_reg[0]){
    TEMP.publish(data_bme[0]);
    PRES.publish(data_bme[1]);
    HUM.publish(data_bme[2]);
  }
  */

}

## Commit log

2019-09-28 fixed mqtt payload size to 2048
    [IOT.ino]
2020-01-19 changed board, added pcp schematics
    [SensorRC2.brd, SensorRC2.sch, SensorRevB.brd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]

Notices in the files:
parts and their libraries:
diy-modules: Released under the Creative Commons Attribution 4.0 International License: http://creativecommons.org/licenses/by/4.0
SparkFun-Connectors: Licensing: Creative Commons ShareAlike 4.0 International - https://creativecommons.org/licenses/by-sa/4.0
